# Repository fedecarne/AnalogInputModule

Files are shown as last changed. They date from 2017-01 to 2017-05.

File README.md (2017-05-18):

This is the repo of the Analog Input Module for Bpod.

This repository contains:

-Firmware for Arduino
-Software API for MATLAB
-Design files for the circuit board
-Design files for the enclosure

Requirements:

- ArCOM (https://github.com/sanworks/ArCOM)

Features:

- Arduino-compatible 180MHz ARM Cortex M4 processor (Teensy 3.6)
- 8 x 12 bit Analog inputs (based on Analog Devices AD7327BRUZ)
- Sampling rate: up to 100kHz (1 channel)
- Voltage range settings: -10V:10V, -5V:5V, -2.5V:2.5V, 0V:10V
- 8GB microSD memory for data storage and retrieval
- 2 UART connections to communicate threshold-crossing events to state machine
- Online streaming of digitalized signal through USB or UART
- MATLAB API for easy configuration and usage during behavioral experiments

To get started:
1. Add this folder 'MATLAB' to the MATLAB path.

2. Create your BpodAnalogIn object (you might need to specify the serial port)

	Ain = BpodAnalogIn('COM14');

3. Run Analog Streamer:

	Ain.Streamer

Check out the [documentation](https://sites.google.com/site/bpodanaloginmodule/analog-input-module).

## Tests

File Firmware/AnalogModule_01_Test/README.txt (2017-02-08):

Test version for the rev 1 of the board. 
SD funcionality commented out.

Add acknowledgement bytes

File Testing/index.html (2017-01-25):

## Bpod 8x Analog Input Module

- Overview
- Features
- User Functions
- Examples
- Performance
  - Static Performance
  - Dynamic Performance
- License

### Overview

The AnalogIn Module adds analog acquisition capabilities to the Bpod ecosystem.

### Features

- 8 input channels (12-bit)
- 20kHz+ sampling
- Input range: -10 to +10V (software selectable to +/- 5 or +/-2.5V and 0 to 10V ranges)
- MicroSD card to store up to XXX seconds of acquired data
- USB interface to stream or retrieve data from memory
- Threshold crossing detection (configurable)
- 2 UART serial interfaces connect the module to:
  - The state machine
  - The analog output module (direct interface for closed loop applications)
- I2C interface supported with the I2C module
- Matlab API
- Powered by Arduino Due

### User Functions

User Functions

### Examples

Examples

### Performance

#### Static Performance

The static performance of the board is characterized by the gain error, offset error and maximum absolute error. Below is the result of acquiring a set of static signals across the voltage range of the board.

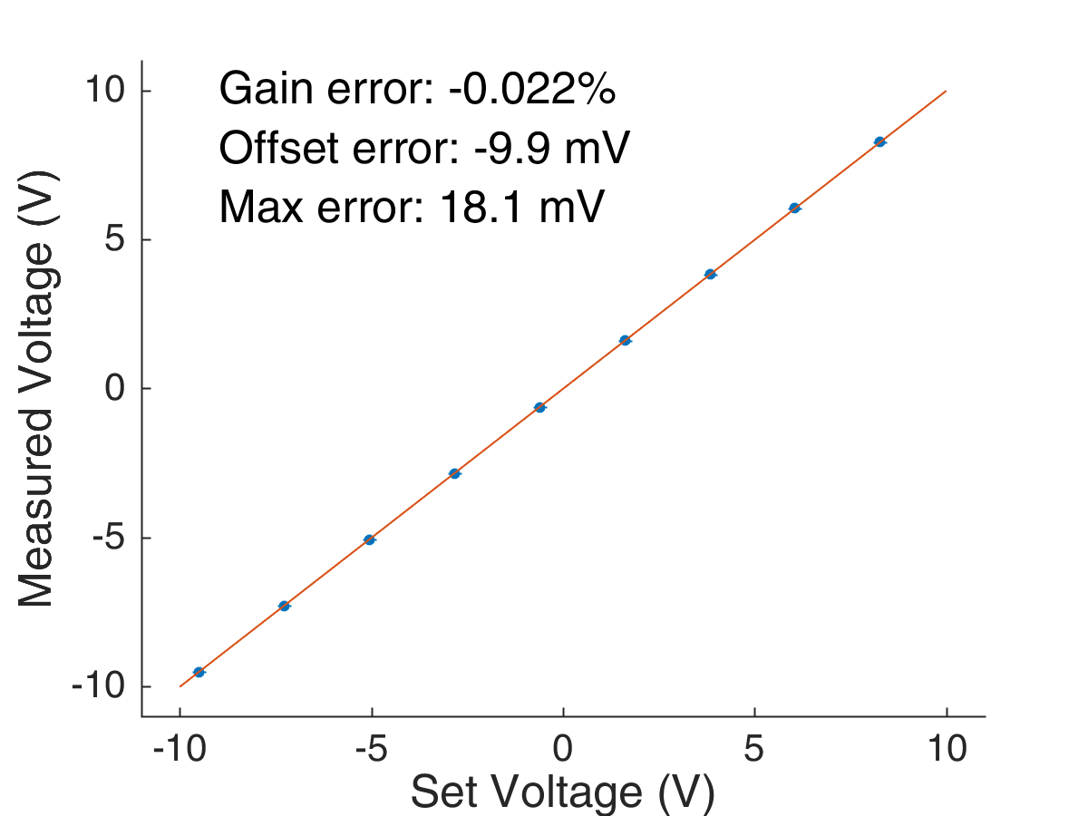
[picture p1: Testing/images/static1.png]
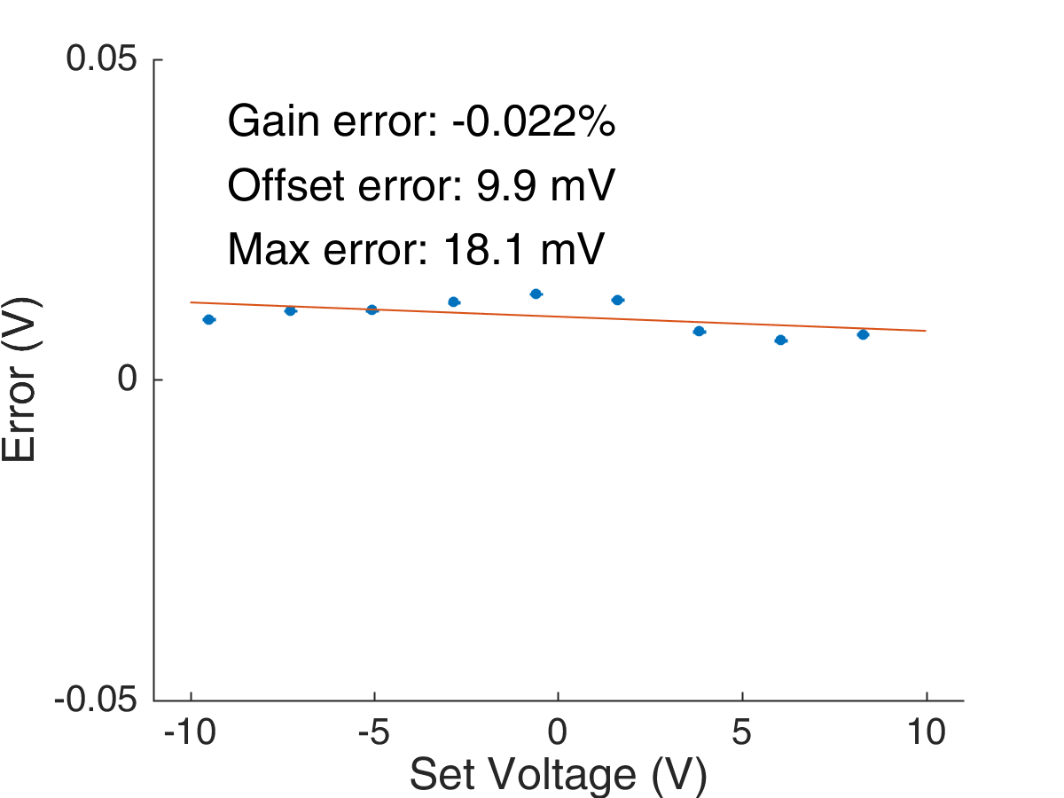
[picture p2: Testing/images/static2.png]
 

#### Dynamic Performance

Signal-to-noise ratio (SNR), total harminic distortion (THD) and signal-to-noise-and-distortion were calculated using a 100Hz signal and sampling at 2kHz.



The SNR does not depend on the sampling frequency up to 20kHz.



### License

License

#### Enjoy! :)

© Copyright? All Rights Reserved.

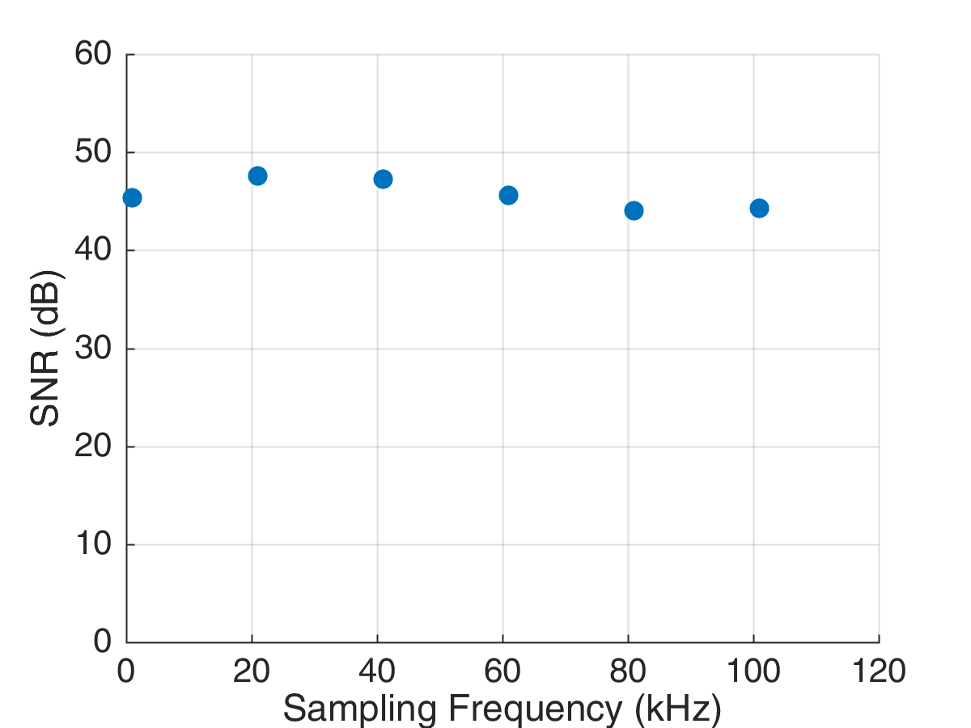
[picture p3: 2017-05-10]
Testing/figs/SnrVsFs.png

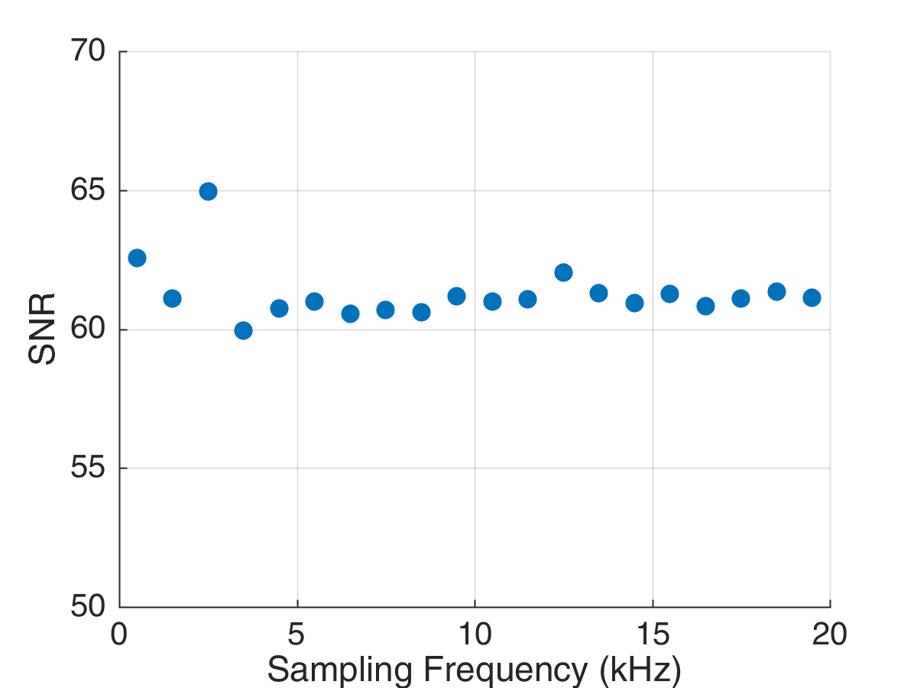
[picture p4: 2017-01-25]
Copy_of_Testing/images/SnrVsFs.png

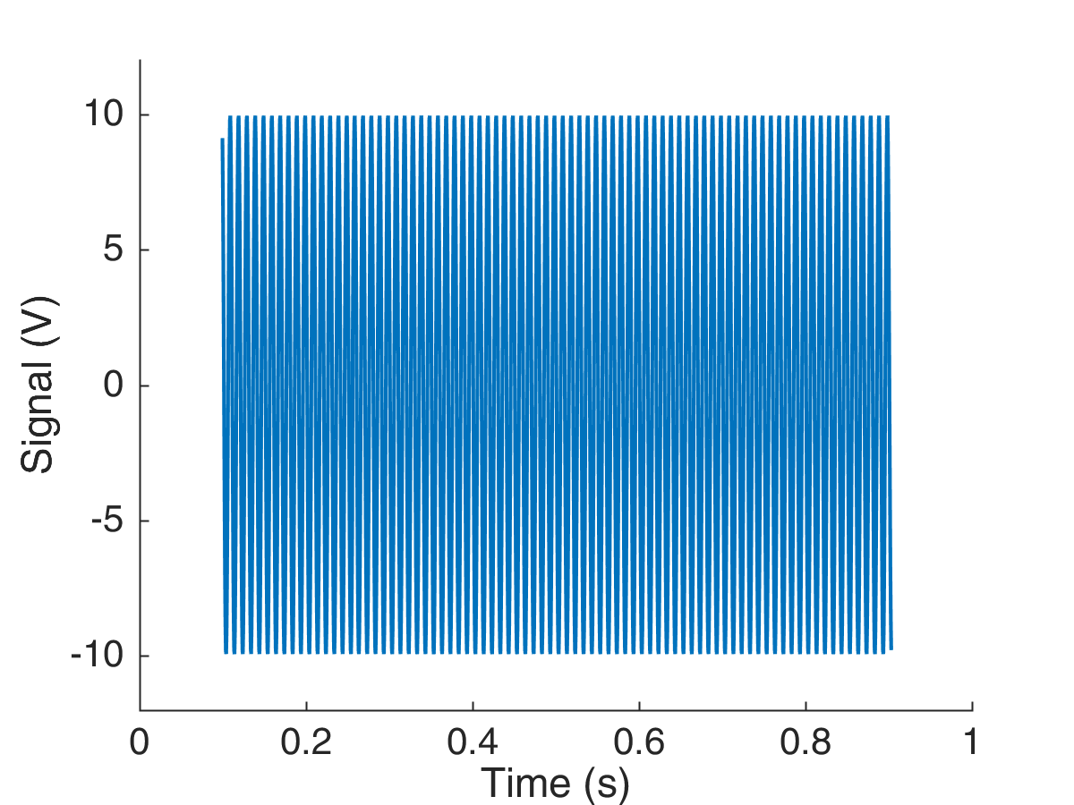
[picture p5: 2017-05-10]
Testing/figs/sine.png

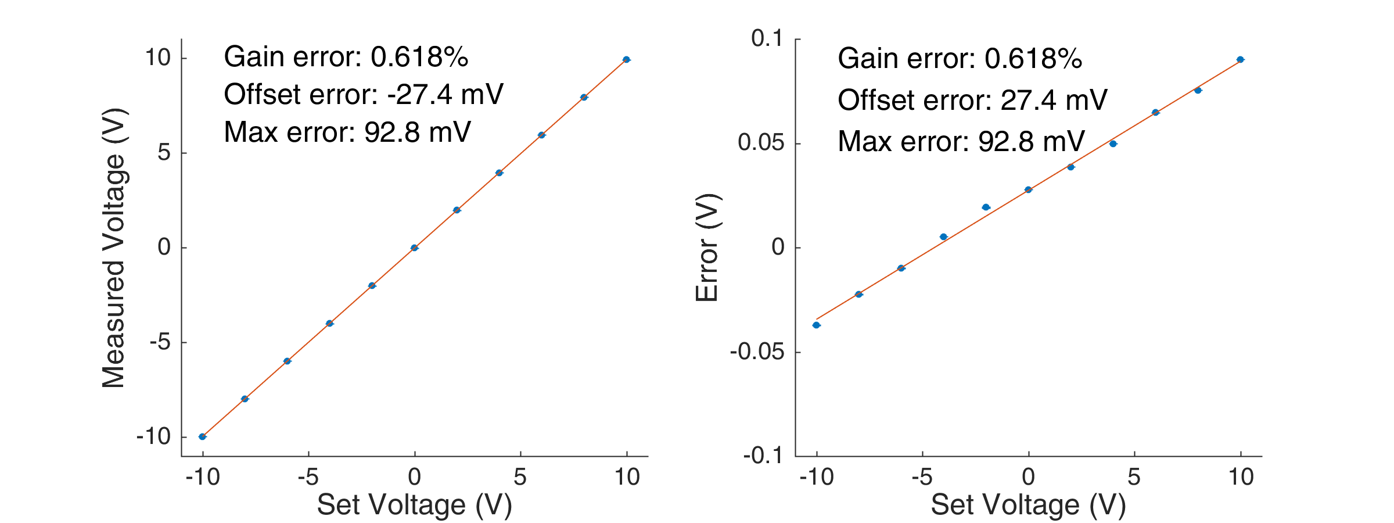
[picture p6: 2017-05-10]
Testing/figs/lite/static.png

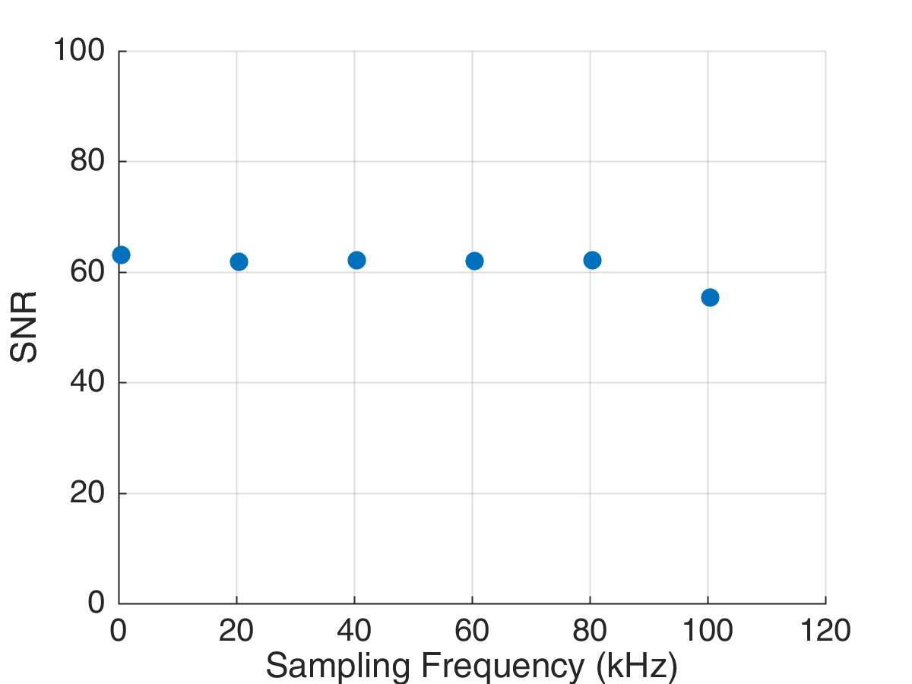
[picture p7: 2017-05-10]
Testing/figs/lite/SnrVsFs.png

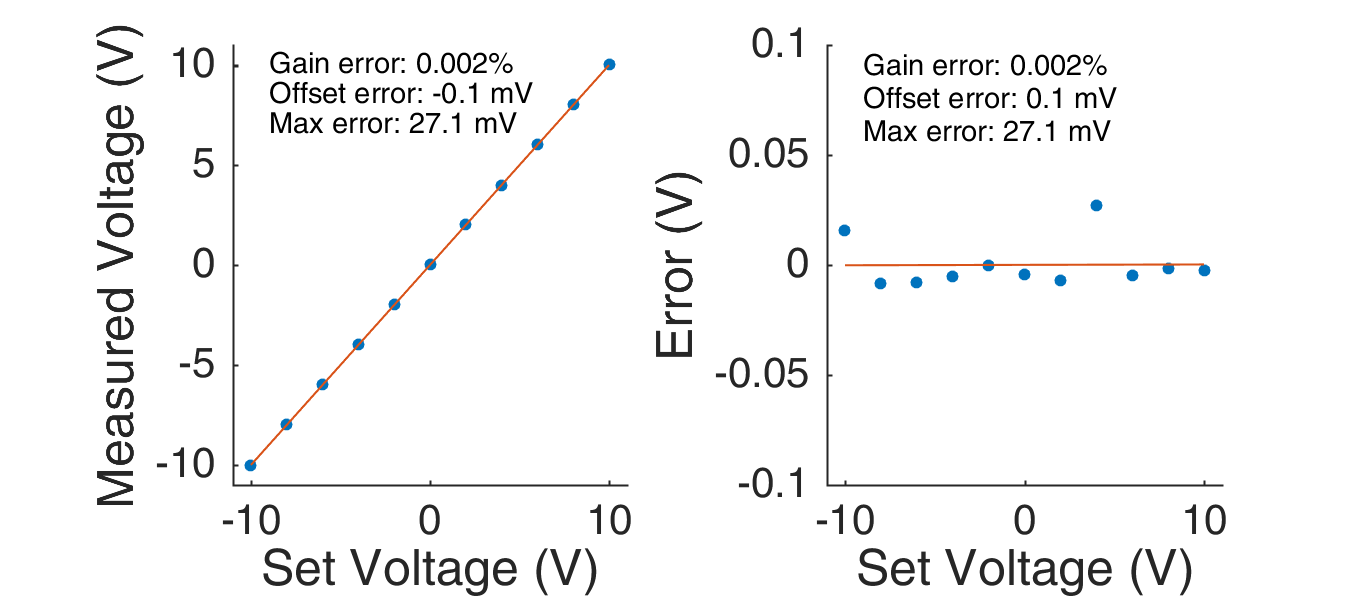
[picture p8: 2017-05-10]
Testing/figs/static.png

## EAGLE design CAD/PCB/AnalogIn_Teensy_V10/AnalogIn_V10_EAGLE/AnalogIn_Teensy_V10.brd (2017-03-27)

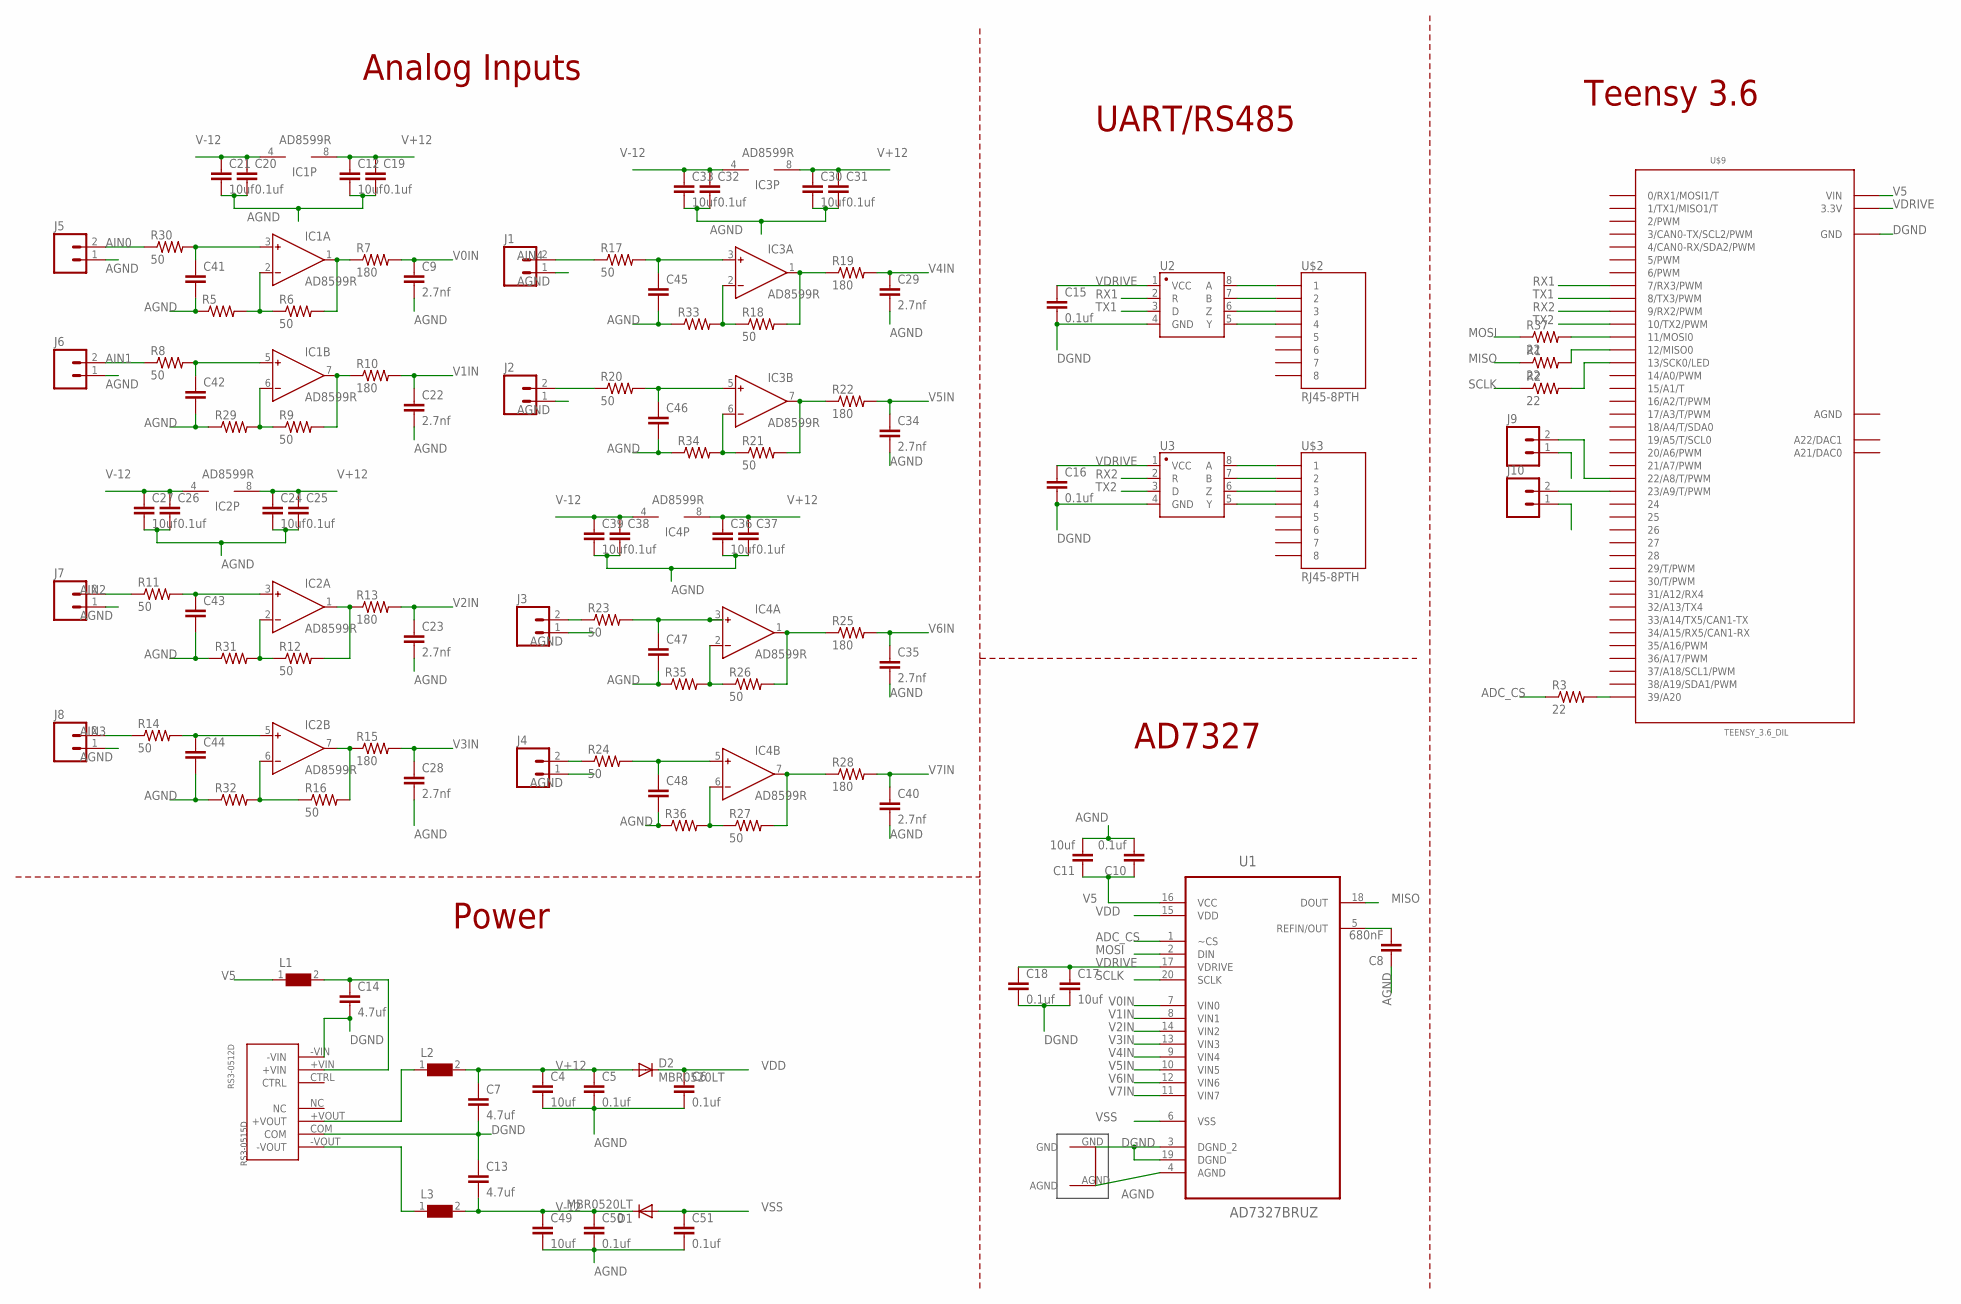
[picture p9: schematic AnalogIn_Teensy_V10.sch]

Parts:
C4, C11, C12, C17, C21, C24, C27, C30, C33, C36, C39, C49: 10uf; 0603-CAP
C5, C6, C10, C15, C16, C18, C19, C20, C25, C26, C31, C32, C37, C38, C50, C51: 0.1uf; 0603-CAP
C7, C13, C14: 4.7uf; 0603-CAP
C8: 680nF; 0603-CAP
C9, C22, C23, C28, C29, C34, C35, C40: 2.7nf; 0603-CAP
C41, C42, C43, C44, C45, C46, C47, C48: CAP0603-CAP; 0603-CAP
D1, D2: MBR0520LT; SOD123
IC1, IC2, IC3, IC4: AD8599R; SO8
J1, J2, J3, J4, J5, J6, J7, J8, J9, J10: M023.5MM; SCREWTERMINAL-3.5MM-2
L1, L2, L3: WE-CBF-742792118_1206; 1206
R1, R2, R3, R37: 22; 0603-RES
R5, R29, R31, R32, R33, R34, R35, R36: RESISTOR0603; 0603-RES
R6, R8, R9, R11, R12, R14, R16, R17, R18, R20, R21, R23, R24, R26, R27, R30: 50; 0603-RES
R7, R10, R13, R15, R19, R22, R25, R28: 180; 0603-RES
RS3-0512D: RS3-0515D
U1: AD7327BRUZ; SOP65P640X120-20N
U2, U3: SN65HVD31DR; SO08
U$2, U$3: RJ45-8PTH; RJ45-8
U$4: GNDPLANESHRT
U$9: TEENSY_3.6_DIL

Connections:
+VOUT: L2.1, RS3-0512D.+VOUT
-VOUT: L3.1, RS3-0512D.-VOUT
ADC_CS: R3.1, U1.1 (~CS)
AGND: C4.2, C5.2, C6.2, C8.1, C9.2, C10.2, C11.2, C12.2, C19.2, C20.2, C21.2, C22.2, C23.2, C24.2, C25.2, C26.2, C27.2, C28.2, C29.2, C30.2, C31.2, C32.2, C33.2, C34.2, C35.2, C36.2, C37.2, C38.2, C39.2, C40.2, C41.2, C42.2, C43.2, C44.2, C45.2, C46.2, C47.2, C48.2, C49.2, C50.2, C51.2, J1.1, J2.1, J3.1, J4.1, J5.1, J6.1, J7.1, J8.1, R5.1, R29.1, R31.1, R32.1, R33.1, R34.1, R35.1, R36.1, U1.4 (AGND), U$4.AGND, U$9.AGND
AIN0: J5.2, R30.1
AIN1: J6.2, R8.1
AIN2: J7.2, R11.1
AIN3: J8.2, R14.1
AIN4: J1.2, R17.1
AIN5: J2.2, R20.1
AIN6: J3.2, R23.1
AIN7: J4.2, R24.1
DGND: C7.2, C13.1, C14.2, C15.2, C16.2, C17.2, C18.2, J9.1, J10.1, RS3-0512D.-VIN, RS3-0512D.COM, U1.3 (DGND_2), U1.19 (DGND), U2.4 (GND), U3.4 (GND), U$4.GND, U$9.GND, U$9.GND1 (GND)
MISO: R1.1, U1.18 (DOUT)
MOSI: R37.1, U1.2 (DIN)
unnamed: U2.6 (Z), U$2.3
unnamed: U2.8 (A), U$2.1
unnamed: U2.5 (Y), U$2.4
unnamed: U2.7 (B), U$2.2
unnamed: U3.6 (Z), U$3.3
unnamed: U3.5 (Y), U$3.4
unnamed: U3.8 (A), U$3.1
unnamed: U3.7 (B), U$3.2
unnamed: R37.2, U$9.11 (11/MOSI0)
unnamed: R1.2, U$9.12 (12/MISO0)
unnamed: C14.1, L1.2, RS3-0512D.+VIN
unnamed: R3.2, U$9.39/A20
unnamed: C41.1, IC1.3 (IN+), R30.2
unnamed: R2.2, U$9.13 (13/SCK0/LED)
unnamed: IC1.2 (IN-), R5.2, R6.1
unnamed: IC1.1 (OUT), R6.2, R7.1
unnamed: J10.2, U$9.23/A9 (23/A9/T/PWM)
unnamed: J9.2, U$9.22/A8 (22/A8/T/PWM)
unnamed: C42.1, IC1.5 (IN+), R8.2
unnamed: IC1.6 (IN-), R9.1, R29.2
unnamed: IC1.7 (OUT), R9.2, R10.1
unnamed: C43.1, IC2.3 (IN+), R11.2
unnamed: IC2.2 (IN-), R12.1, R31.2
unnamed: IC2.1 (OUT), R12.2, R13.1
unnamed: C44.1, IC2.5 (IN+), R14.2
unnamed: IC2.6 (IN-), R16.1, R32.2
unnamed: IC2.7 (OUT), R15.1, R16.2
unnamed: C45.1, IC3.3 (IN+), R17.2
unnamed: IC3.2 (IN-), R18.1, R33.2
unnamed: IC3.1 (OUT), R18.2, R19.1
unnamed: C46.1, IC3.5 (IN+), R20.2
unnamed: IC3.6 (IN-), R21.1, R34.2
unnamed: IC3.7 (OUT), R21.2, R22.1
unnamed: C47.1, IC4.3 (IN+), R23.2
unnamed: IC4.2 (IN-), R26.1, R35.2
unnamed: IC4.1 (OUT), R25.1, R26.2
unnamed: C48.1, IC4.5 (IN+), R24.2
unnamed: IC4.6 (IN-), R27.1, R36.2
unnamed: IC4.7 (OUT), R27.2, R28.1
REF: C8.2, U1.5 (REFIN/OUT)
RX1: U2.2 (R), U$9.7 (7/RX3/PWM)
RX2: U3.2 (R), U$9.9 (9/RX2/PWM)
SCLK: R2.1, U1.20 (SCLK)
TX1: U2.3 (D), U$9.8 (8/TX3/PWM)
TX2: U3.3 (D), U$9.10 (10/TX2/PWM)
V0IN: C9.1, R7.2, U1.7 (VIN0)
V1IN: C22.1, R10.2, U1.8 (VIN1)
V2IN: C23.1, R13.2, U1.14 (VIN2)
V3IN: C28.1, R15.2, U1.13 (VIN3)
V4IN: C29.1, R19.2, U1.9 (VIN4)
V5: C10.1, C11.1, L1.1, U1.16 (VCC), U$9.VIN
V5IN: C34.1, R22.2, U1.10 (VIN5)
V6IN: C35.1, R25.2, U1.12 (VIN6)
V7IN: C40.1, R28.2, U1.11 (VIN7)
V+12: C4.1, C5.1, C7.1, C12.1, C19.1, C24.1, C25.1, C30.1, C31.1, C36.1, C37.1, D2.A, IC1.8 (V+), IC2.8 (V+), IC3.8 (V+), IC4.8 (V+), L2.2
V-12: C13.2, C20.1, C21.1, C26.1, C27.1, C32.1, C33.1, C38.1, C39.1, C49.1, C50.1, D1.C, IC1.4 (V-), IC2.4 (V-), IC3.4 (V-), IC4.4 (V-), L3.2
VDD: C6.1, D2.C, U1.15 (VDD)
VDRIVE: C15.1, C16.1, C17.1, C18.1, U1.17 (VDRIVE), U2.1 (VCC), U3.1 (VCC), U$9.3.3V, U$9.3.3V3 (3.3V)
VSS: C51.1, D1.A, U1.6 (VSS)

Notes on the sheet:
Teensy 3.6
UART/RS485
AD7327
Analog Inputs
Power

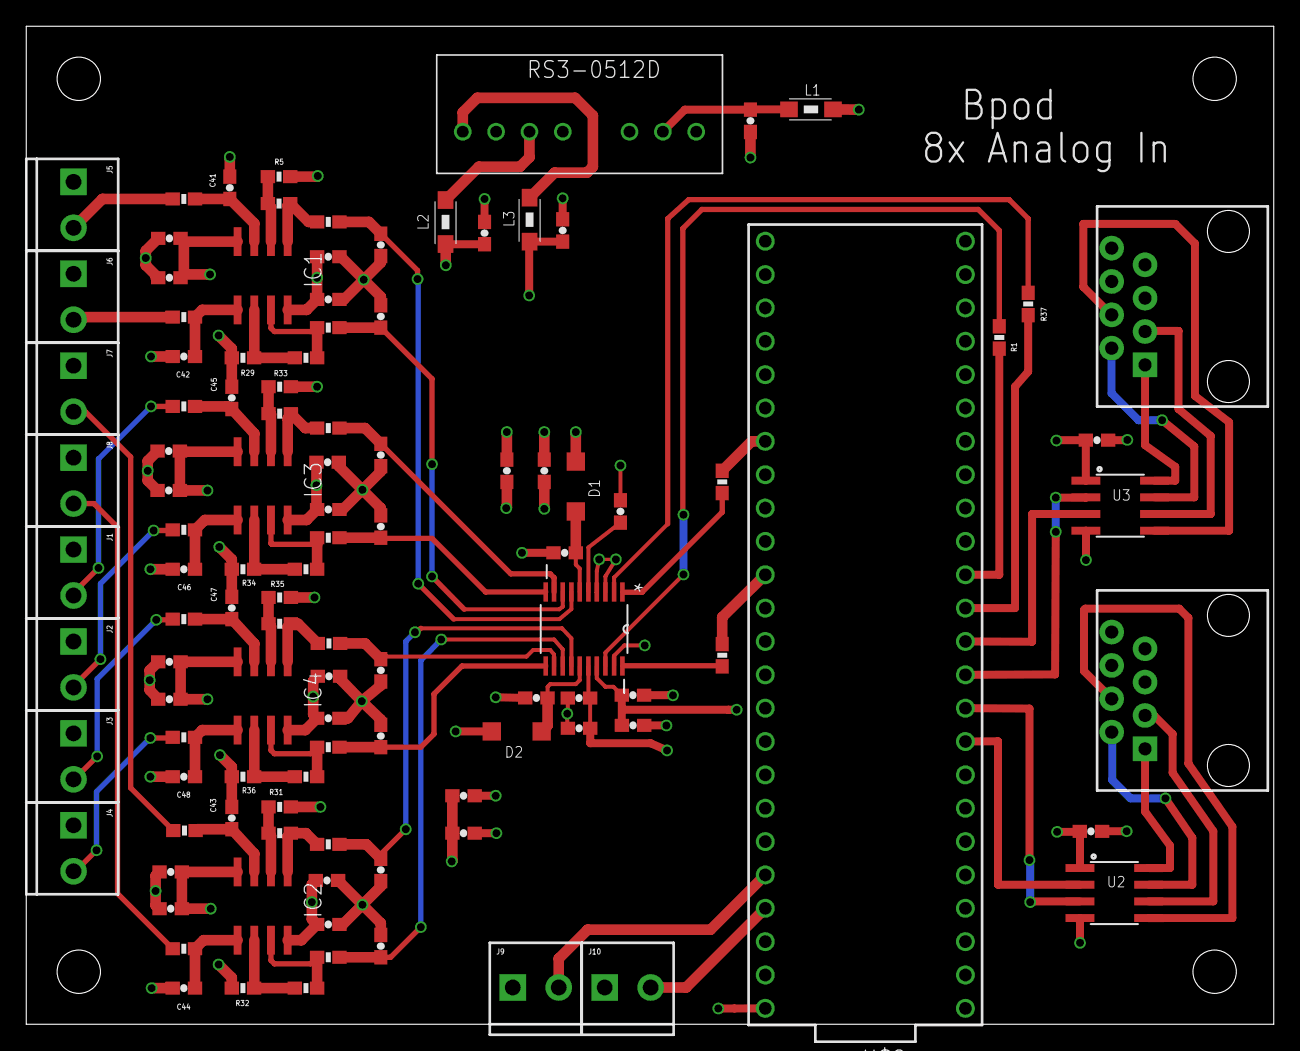
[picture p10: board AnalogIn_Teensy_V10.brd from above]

Board: 4 copper layers, 95.0 x 76.0 mm, 115 parts (0 on the bottom side), 74 nets.

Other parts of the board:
U$5, U$6, U$7, U$8: STAND-OFF

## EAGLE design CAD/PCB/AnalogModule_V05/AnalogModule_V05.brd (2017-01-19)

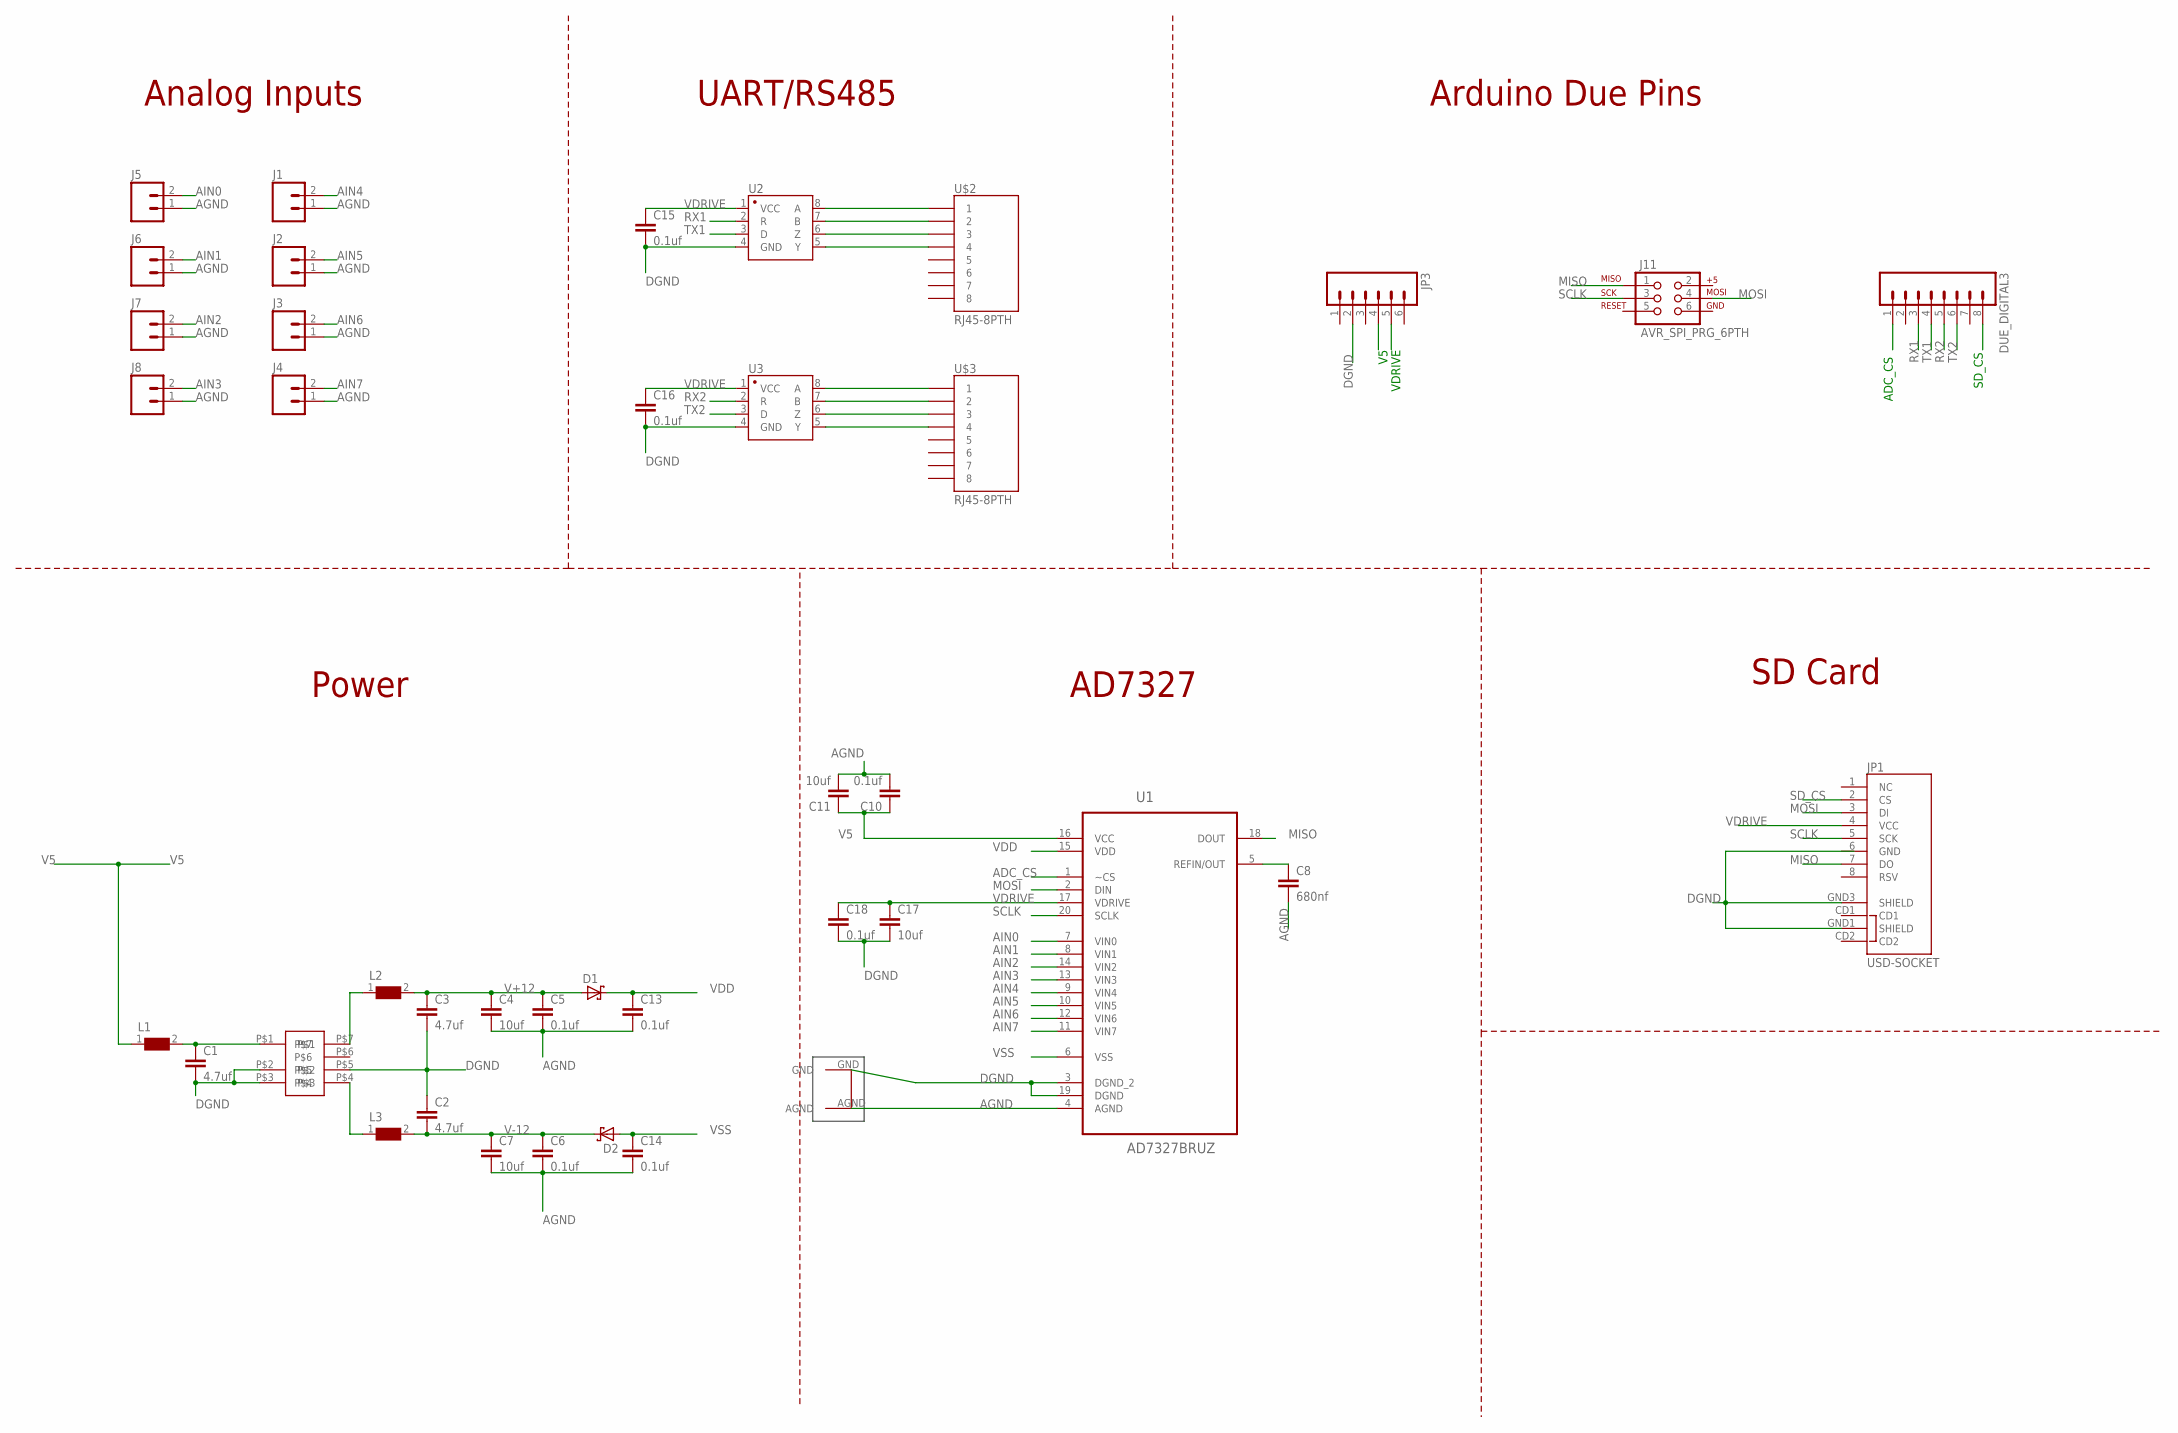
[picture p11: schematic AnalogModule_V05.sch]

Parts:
C1, C2, C3: 4.7uf; 1206
C4, C7: 10uf; 1206
C5, C6, C13, C14: 0.1uf; 1206
C8: 680nf; 1206
C10, C15, C16, C18: 0.1uf; 0603-CAP
C11, C17: 10uf; 0603-CAP
D1, D2: SCHOTTKY-DIODESMD; SMB
DUE_DIGITAL3: M081X08; 1X08
J1, J2, J3, J4, J5, J6, J7, J8: M023.5MM; SCREWTERMINAL-3.5MM-2
J11: AVR_SPI_PRG_6PTH; 2X3
JP1: USD-SOCKET; MICROSD_1:1
JP3: M06SILK_FEMALE_PTH; 1X06
L1, L2, L3: WE-CBF-742792118_1206; 1206
U1: AD7327BRUZ; SOP65P640X120-20N
U2, U3: SN65HVD31DR; SO08
U$1: TDK_LAMBDA_5_TO_BI_12_125MA
U$2, U$3: RJ45-8PTH; RJ45-8
U$4: GNDPLANESHRT

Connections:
ADC_CS: DUE_DIGITAL3.1, U1.1 (~CS)
AGND: C4.2, C5.2, C6.2, C7.2, C8.2, C10.2, C11.2, C13.2, C14.2, J1.1, J2.1, J3.1, J4.1, J5.1, J6.1, J7.1, J8.1, U1.4 (AGND), U$4.AGND
AIN0: J5.2, U1.7 (VIN0)
AIN1: J6.2, U1.8 (VIN1)
AIN2: J7.2, U1.14 (VIN2)
AIN3: J8.2, U1.13 (VIN3)
AIN4: J1.2, U1.9 (VIN4)
AIN5: J2.2, U1.10 (VIN5)
AIN6: J3.2, U1.12 (VIN6)
AIN7: J4.2, U1.11 (VIN7)
DGND: C1.2, C2.1, C3.2, C15.2, C16.2, C17.2, C18.2, JP1.GND1 (SHIELD), JP1.GND3 (SHIELD), JP3.2, U1.3 (DGND_2), U1.19 (DGND), U2.4 (GND), U3.4 (GND), U$1.P$2, U$1.P$3, U$1.P$5, U$4.GND
MISO: J11.1, JP1.7 (DO), U1.18 (DOUT)
MOSI: J11.4, JP1.3 (DI), U1.2 (DIN)
unnamed: U2.6 (Z), U$2.3
unnamed: U2.8 (A), U$2.1
unnamed: U2.5 (Y), U$2.4
unnamed: U2.7 (B), U$2.2
unnamed: U3.6 (Z), U$3.3
unnamed: U3.5 (Y), U$3.4
unnamed: U3.8 (A), U$3.1
unnamed: U3.7 (B), U$3.2
unnamed: C1.1, L1.2, U$1.P$1
unnamed: L2.1, U$1.P$7
unnamed: L3.1, U$1.P$4
REF: C8.1, U1.5 (REFIN/OUT)
RX1: DUE_DIGITAL3.3, U2.2 (R)
RX2: DUE_DIGITAL3.5, U3.2 (R)
SCLK: J11.3, JP1.5 (SCK), U1.20 (SCLK)
SD_CS: DUE_DIGITAL3.8, JP1.2 (CS)
TX1: DUE_DIGITAL3.4, U2.3 (D)
TX2: DUE_DIGITAL3.6, U3.3 (D)
V5: C10.1, C11.1, JP3.4, L1.1, U1.16 (VCC)
V+12: C3.1, C4.1, C5.1, D1.A, L2.2
V-12: C2.2, C6.1, C7.1, D2.C, L3.2
VDD: C13.1, D1.C, U1.15 (VDD)
VDRIVE: C15.1, C16.1, C17.1, C18.1, JP1.4 (VCC), JP3.5, U1.17 (VDRIVE), U2.1 (VCC), U3.1 (VCC)
VSS: C14.1, D2.A, U1.6 (VSS)

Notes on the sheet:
Arduino Due Pins
UART/RS485
SD Card
AD7327
Analog Inputs
Power
ADC_CS
VDRIVE
SD_CS

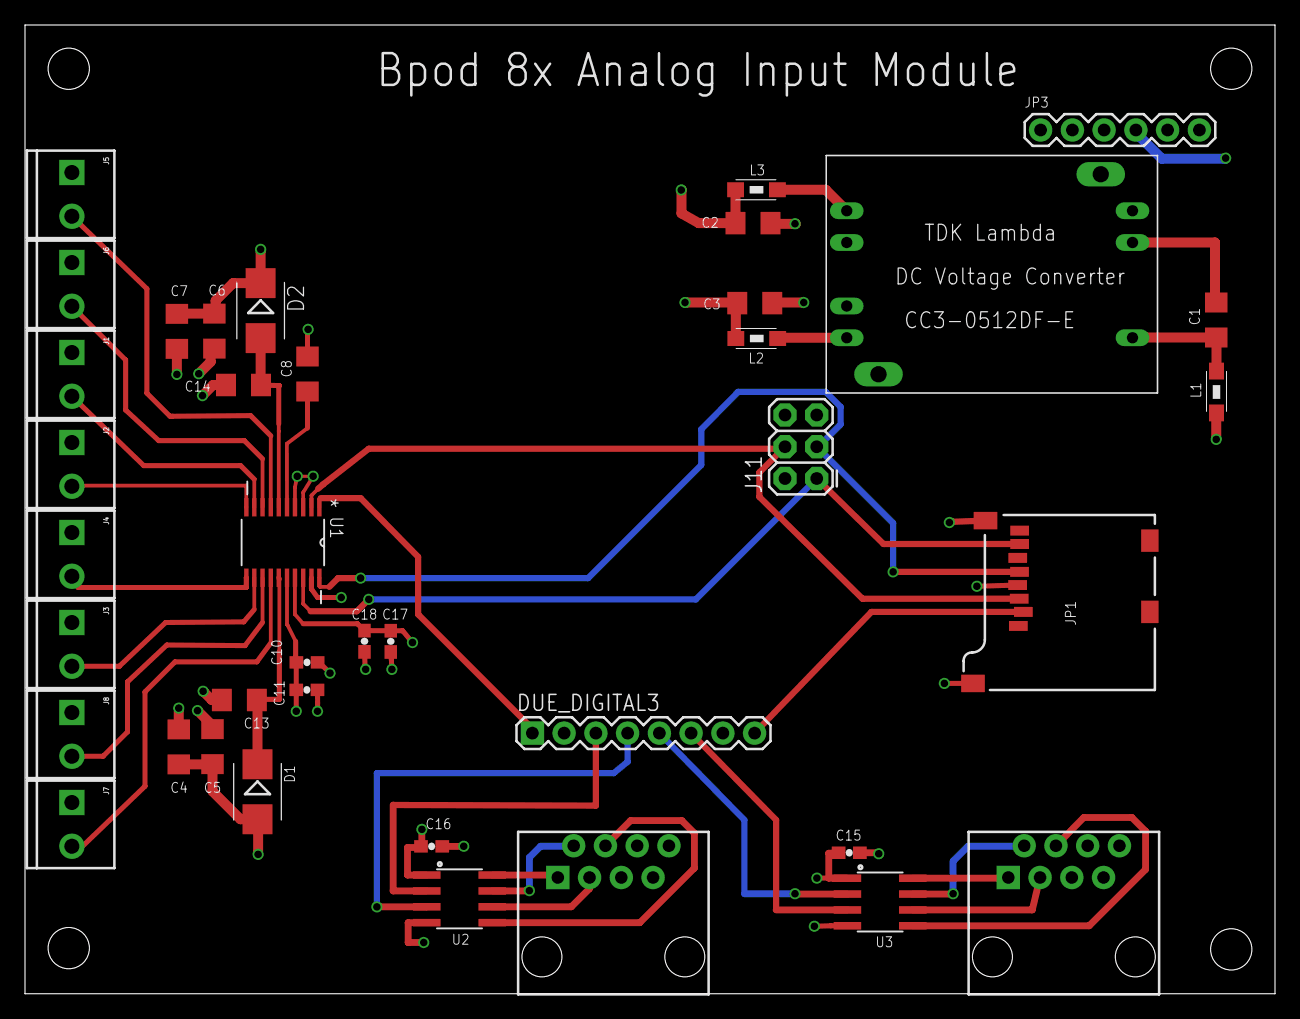
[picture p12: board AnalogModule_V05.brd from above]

Board: 4 copper layers, 100.0 x 77.5 mm, 44 parts (0 on the bottom side), 37 nets.

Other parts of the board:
U$5, U$6, U$7, U$8: STAND-OFF

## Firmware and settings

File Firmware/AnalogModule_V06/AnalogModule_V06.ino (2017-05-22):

// Analog Module firmware v4.0.0
// Federico Carnevale, October 2016

// ** DEPENDENCIES YOU NEED TO INSTALL FIRST **

// This firmware uses the sdFat library, developed by Bill Greiman. (Thanks Bill!!)
// Download it from here: https://github.com/greiman/SdFat
// and copy it to your /Arduino/Libraries folder.

#include "ArCOM.h"
#include "AD7327.h"
#include <SPI.h>
#include <SdFat.h>
SdFatSdioEX SD;

#define SERIAL_TX_BUFFER_SIZE 256
#define SERIAL_RX_BUFFER_SIZE 256

// Module setup
unsigned long FirmwareVersion = 1;
char moduleName[] = "AnalogIn"; // Name of module for manual override UI and state machine assembler

AD7327 AD(39); // ADC ChipSelect
byte adcChipSelectPin = 39; //DISCARD

ArCOM USBCOM(SerialUSB); // Creates an ArCOM object called USBCOM, wrapping SerialUSB
ArCOM StateMachineCOM(Serial3); // Creates an ArCOM object called StateMachineCOM
ArCOM OutputStreamCOM(Serial2);

// Variables that define other hardware pins
byte DebugPin = 18; // Teensy LED

// System objects
SPISettings ADCSettings(10000000, MSBFIRST, SPI_MODE2);
IntervalTimer hardwareTimer; // Hardware timer to ensure even sampling
File DataFile; // File on microSD card, to store waveform data

// Op menu variable
byte opCode = 0; // Serial inputs access an op menu. The op code byte stores the intended operation.
byte opSource = 0; // 0 = op from USB, 1 = op from UART1, 2 = op from UART2. More op code menu options are exposed for USB.
boolean newOpCode = 0; // true if an opCode was read from one of the ports
byte OpMenuByte = 213; // This byte must be the first byte in any serial transmission. Reduces the probability of interference from port-scanning software

// All channels active by default
const byte nPhysicalChannels = 8;
byte nActiveChannels = 8;

// Actions
boolean StreamSignalToUSB = false; // Stream one channel to AnalogStreamer
boolean StreamEventsToUSB = false; // Stream event detection to AnalogStreamer
boolean LoggingDataToSD = false; // Logs active channels to SD card
boolean SendingEventsToBpod = false; // Send threshold crossing by serial port
boolean SendingDataToSerial = false; // Send adc reads through serial port

// State variables
byte ChannelToStream = 0;
byte SelectedADCRange = 0;
boolean acquiring = false; // true if acquiring from the ADC
uint32_t samplingRate = 1000; // in Hz 

// Threshold crossing events
boolean triggered[] = {0, 0, 0, 0, 0, 0, 0, 0};
unsigned long ThresholdValue[] = {0, 0, 0, 0, 0, 0, 0, 0};
unsigned long ResetValue[] = {0, 0, 0, 0, 0, 0, 0, 0};

// SD variables
uint32_t nFullBufferReads = 0; // Number of full buffer reads in transmission
uint32_t nRemainderBytes = 0; // Number of bytes remaining after full transmissions
const uint32_t sdReadBufferSize = 1024; // in bytes
uint8_t sdReadBuffer[sdReadBufferSize*2];

// Other variables
uint16_t adcDigitalValue = 0;
uint32_t nSamplesAcquired = 0;
uint32_t maxSamplesToAcquire = 0; // 0 = infinite
byte VoltageRangeArray[nPhysicalChannels] = {0};

// Error messages stored in flash.
#define error(msg) sd.errorHalt(F(msg))

void setup() {
  pinMode(DebugPin, OUTPUT);
  digitalWrite(DebugPin, HIGH);
  Serial2.begin(1312500); 
  Serial3.begin(1312500);
  SPI.begin();
  SD.begin(); // Initialize microSD card
  hardwareTimer.begin(handler, (1/(double)samplingRate)*1000000); // hardwareTimer is an interval timer object - Teensy 3.6's hardware timer
}


void loop() {
  
}

void handler(void) {
  if (StateMachineCOM.available() > 0) {
    opCode = StateMachineCOM.readByte(); // Read in an op code
    opSource = 1; // UART 1
    newOpCode = true;
  } else if (OutputStreamCOM.available() > 0) {
    opCode = OutputStreamCOM.readByte();
    opSource = 2; // UART 2
    newOpCode = true;
  } else if (USBCOM.available() > 0) {
    if (USBCOM.readByte() == OpMenuByte) {
      opCode = USBCOM.readByte();
      opSource = 0; // USB
    };
    newOpCode = true;
  }

  if (newOpCode) { // If an op byte arrived from one of the serial interfaces
    newOpCode = false;
    switch (opCode) {
      case 'O': {
          if (opSource == 0) {
            USBCOM.writeByte(161); // Send acknowledgement byte
            USBCOM.writeUint32(FirmwareVersion); // Send firmware version
            StreamSignalToUSB = false;
            StreamEventsToUSB = false;
            LoggingDataToSD = false;
            SendingEventsToBpod = false;
            SendingDataToSerial = false;
            DataFile.close();
          }
        } break;

      case 255: // Return Bpod module info
        if (opSource == 1) { // Only returns this info if requested from state machine device
          returnModuleInfo();
        } break;

      case 'S': { // Start USB streaming signal
          StreamSignalToUSB = true;
        } break;

      case 'X': { // Stop USB streaming signal
          StreamSignalToUSB = false;
        } break;

      case 'C': { // Select Channel
          ChannelToStream = USBCOM.readByte(); // Read the command byte (an op code for the operation to execute)
          if (ChannelToStream > 7) {
            ChannelToStream = 0;
          }
        } break;

      case 'R': { // Select ADC Voltage range
          USBCOM.readByteArray(VoltageRangeArray, nActiveChannels);
          for (int i = 0; i > nPhysicalChannels; i++) {
            AD.setRange(i, VoltageRangeArray[i]);
          }
        } break;

      case 'A': { // Set number of active channels
          nActiveChannels = USBCOM.readByte();
          USBCOM.writeByte(1); // Send confirm byte
        } break;

      case 'E': { // Start streaming events
          StreamEventsToUSB = true;
          for (int i = 0; i < nPhysicalChannels; i++) {
            triggered[i] = 0;
          }
        } break;

      case 'Y': { // Stop  streaming events
          StreamEventsToUSB = false;
          stopAcquiringIfNotActive();
        } break;

      case 'B': { // Set reset values
          for (int i = 0; i < nPhysicalChannels; i++) {
            ResetValue[i] = USBCOM.readUint32();
          }
        } break;

      case 'T': { // Set thresholds
          for (int i = 0; i < nPhysicalChannels; i++) {
            ThresholdValue[i] = USBCOM.readUint32();
          }
        } break;

      case 'L': { // Start logging data
          //StateMachineCOM.writeChar(1); // Uncomment to send start logging flag to bpod for diagnostics (NOTE: may be confused with a threshold event if streaming events)
          StartLogData();
        } break;

      case 'Z': { // Stop  logging data
          StopLogData();
          stopAcquiringIfNotActive();
        } break;

      case 'D': { // Read SD card and send data

          LoggingDataToSD = false;
          DataFile.close();
          unsigned long d0;
          DataFile = SD.open("Data.wfm", FILE_WRITE);
          DataFile.seekSet(0);
          if (nSamplesAcquired*2 > sdReadBufferSize) {
            nFullBufferReads = (unsigned long)(floor(((double)nSamplesAcquired)*double(nActiveChannels)*2 / (double)sdReadBufferSize));
          } else {
            nFullBufferReads = 0;
          }
          USBCOM.writeUint32(nSamplesAcquired);     
          for (int i = 0; i < nFullBufferReads; i++) { // Full buffer transfers; skipped if nFullBufferReads = 0
            DataFile.read(sdReadBuffer, sdReadBufferSize);
            USBCOM.writeByteArray(sdReadBuffer, sdReadBufferSize);
          }
          nRemainderBytes = (nSamplesAcquired*nActiveChannels*2)-(nFullBufferReads*sdReadBufferSize);
          if (nRemainderBytes > 0) {
            DataFile.read(sdReadBuffer, nRemainderBytes);
            USBCOM.writeByteArray(sdReadBuffer, nRemainderBytes);     
          }
          DataFile.close();
        } break;

      case 'P': { // Change sampling frequency
          samplingRate = USBCOM.readUint32();
          hardwareTimer.end();
          hardwareTimer.begin(handler, (1/(double)samplingRate)*1000000);
        } break;

      case 'N': { // Start sending threshold crossing events to bpod
          for (int i = 0; i < nPhysicalChannels; i++) {
            triggered[i] = 0;
          }
          SendingEventsToBpod = true;
          acquiring = true;
        } break;

      case 'M': { // Stop sending threshold crossing events to bpod
          SendingEventsToBpod = false;
          stopAcquiringIfNotActive();
        } break;

      case 'H': { // Start sending adc reads to serial port
          SendingDataToSerial = true;
          acquiring = true;
        } break;

      case 'I': { // Stop  sending adc reads to serial port
          SendingDataToSerial = false;
          stopAcquiringIfNotActive();
        } break;

      case 'W': {
        maxSamplesToAcquire = USBCOM.readUint32();
        USBCOM.writeByte(1);
      } break;
    }// end switch(opCode)
  }// end newOpCode

  if (acquiring) {
    AD.readADC(); // Reads all active channels and stores the result in a buffer in the AD object: AD.analogData[]
  }

  // Streaming data with AnalogStreamer
  if (StreamSignalToUSB) {
    USBCOM.writeUint16(AD.analogData.uint16[ChannelToStream]);
  }

  // Streaming threshold crossings with AnalogStreamer
  if (StreamEventsToUSB) {
    USBCOM.writeUint8(StreamThresholdCrossing());
  }
  
  if (LoggingDataToSD) {
    LogData();
  }
  if (SendingEventsToBpod) {
    SendThresholdCrossingEvents();
  }
  if (SendingDataToSerial) {
    SendDataToSerial();
  }
} // End main timer loop

// Detect thresholds in active channels and send events to Bpod
void SendThresholdCrossingEvents() {

  // nActiveChannels has the number of active channels
  for (int i = 0; i < nActiveChannels; i++) {
    if (triggered[i] == 0) {
      if (AD.analogData.uint16[i] > ThresholdValue[i]) {
        StateMachineCOM.writeByte(i + 1);
        triggered[i] = 1;
      }
    } else {
      if (AD.analogData.uint16[i] < ResetValue[i]) {
        triggered[i] = 0;
      }
    }
  }
}

// Send data to serial port
void SendDataToSerial() {
  StateMachineCOM.writeByte('R');
  StateMachineCOM.writeUint16Array(AD.analogData.uint16, nActiveChannels);
}

// Log data
void LogData() {
  //Write data to SD
  unsigned long Pos = 0;
  for (int i = 0; i < nActiveChannels; i++) {
    DataFile.write(AD.analogData.uint8[Pos]);
    DataFile.write(AD.analogData.uint8[Pos+1]);
    Pos += 2;
  }
  nSamplesAcquired++;
  if (nSamplesAcquired == maxSamplesToAcquire) {
    StopLogData();
    stopAcquiringIfNotActive();
  }
}

// Log data
void StartLogData() {
  LoggingDataToSD = true;
  acquiring = true;
  SD.remove("Data.wfm");
  DataFile = SD.open("Data.wfm", FILE_WRITE);
  nSamplesAcquired = 0;
}

void StopLogData() {

  LoggingDataToSD = false;
  StateMachineCOM.writeByte(10); // Send stop logging flag to bpod

  // Close logging file
  DataFile.close();
}

void stopAcquiringIfNotActive() {
  if (!StreamEventsToUSB && !LoggingDataToSD && !SendingEventsToBpod && !SendingDataToSerial) {
    acquiring = false;
  }
}

//Function to detect thresholds read all channels of the ADC in sequence
byte StreamThresholdCrossing() {
  byte ThresholdCrossed = 0;
  for (int i = 0; i < nPhysicalChannels; i++) {
    if (triggered[i] == 0) {
      if (AD.analogData.uint16[i] > ThresholdValue[i]) {
        ThresholdCrossed = ThresholdCrossed | 1 << i;
        triggered[i] = 1;
      } else {
        ThresholdCrossed = ThresholdCrossed | 0 << i;
      }
    } else {
      ThresholdCrossed = ThresholdCrossed | 0 << i;

      if (AD.analogData.uint16[i] < ResetValue[i]) {
        triggered[i] = 0;
      }
    }
  }
  return ThresholdCrossed; // Returns the value from the function
}

void returnModuleInfo() {
  StateMachineCOM.writeByte(65); // Acknowledge
  StateMachineCOM.writeUint32(FirmwareVersion); // 4-byte firmware version
  StateMachineCOM.writeByte(sizeof(moduleName) - 1); // Length of module name
  StateMachineCOM.writeCharArray(moduleName, sizeof(moduleName) - 1); // Module name
  StateMachineCOM.writeByte(0);
}

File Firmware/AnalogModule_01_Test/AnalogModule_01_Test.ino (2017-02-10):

// Analog Module firmware v1.0.0
// Federico Carnevale, October 2016
//
// ** DEPENDENCIES YOU NEED TO INSTALL FIRST **

// 1. This firmware uses the open source DueTimer library, developed by Ivan Seidel. (Thanks Ivan!!)
// Download it from here: https://github.com/ivanseidel/DueTimer
// and copy it to your /Arduino/Libraries folder.
// The DueTimer library is open source, and protected by the MIT License.

// 2. This firmware uses the sdFat library, developed by Bill Greiman. (Thanks Bill!!)
// Download it from here: https://github.com/greiman/SdFat
// and copy it to your /Arduino/Libraries folder.

// ** Next, upload the firmware to Arduino Due **
// See here for driver installation and upload instructions: https://www.arduino.cc/en/Guide/ArduinoDue


#include <DueTimer.h>
#include <stdio.h>
#include <stdint.h>
#include <SPI.h>

//#include <SdFat.h>
//#include <SdFatUtil.h>

#include <ArCOM.h> // ArCOM is a serial interface wrapper developed by Sanworks, to streamline transmission of datatypes and arrays over serial

ArCOM myUSB(SerialUSB); // Creates an ArCOM object called myUSB, wrapping SerialUSB

// Define macros for compressing sequential bytes read from the serial port into long and short ints
#define makeUnsignedLong(msb, byte2, byte3, lsb) ((msb << 24) | (byte2 << 16) | (byte3 << 8) | (lsb))
#define makeUnsignedShort(msb, lsb) ((msb << 8) | (lsb))

const uint32_t SAMPLE_INTERVAL_US = 250000;
#define CSV_DELIM ','

byte FirmwareVersion = 1;

// Variables that define other hardware pins
byte adcChipSelectPin = 21; // set pin 8 as the chip select for the ADC:
//byte SDChipSelectPin = 14; // set pin 4 as the chip select for the SD

// Variables for SPI bus
SPISettings ADCSettings(1000000, MSBFIRST, SPI_MODE2);

// Relavant bitmasks for data value and channel address
byte adcValueMask_byte1 = 0b00111111;
byte adcValueMask_byte2 = 0b11111111;
byte adcAddressMask = 0b11100000;

// Default values for ADC

// All channels active by default
byte ActiveChannelsByte = 255; //all channels
int ActiveChannelsList[] = {0,1,2,3,4,5,6,7};
int nActiveChannels = 8;

// Sets control register (8 single-ended inputs, straight binary, internal reference, no sequence)
byte adcControlRegister_byte1 = 0b10000000; 
byte adcControlRegister_byte2 = 0b00110000;

byte adcSequenceRegister_byte1 = 0b11111111;
byte adcSequenceRegister_byte2 = 0b11100000;

byte adcRangeRegister1_byte1 = 0b10111111; // Sets channels 0-3 range to 0V - 10V
byte adcRangeRegister1_byte2 = 0b11100000; // Sets channels 0-3 range to 0V - 10V
byte adcRangeRegister2_byte1 = 0b11011111;  // Sets channels 4-7 range to 0V - 10V
byte adcRangeRegister2_byte2 = 0b11100000;  // Sets channels 4-7 range to 0V - 10V
  
  
// Variables used in programming
byte OpMenuByte = 213; // This byte must be the first byte in any serial transmission. Reduces the probability of interference from port-scanning software

// Actions
boolean StreamSignalToUSB = 0; // Stream one channel to AnalogStreamer
boolean StreamEventsToUSB = 0; // Stream event detection to AnalogStreamer
boolean LoggingDataToSD = 0; // Logs active channels to SD card
boolean SendingEventsToBpod = 0; // Send threshold crossing by serial port

byte ChannelToStream = 0;
byte SelectedADCRange = 0;

byte BrokenBytes[4] = {0}; // Used to store sequential bytes when converting bytes to short and long ints
byte inByte; byte inByte2; byte inByte3; byte inByte4; byte CommandByte; byte BpodCommandByte;

boolean triggered[] = {0,0,0,0,0,0,0,0};
unsigned long ThresholdValue[] = {0,0,0,0,0,0,0,0};
unsigned long ResetValue[] = {0,0,0,0,0,0,0,0};


// SD variables
uint8_t buf[1];
uint8_t buf2[2];
uint8_t buf4[4];

#define FILE_BASE_NAME "Data2"
unsigned long SystemTime = 0;

//SdFat sd;
//SdFile DataFile;

char fileName[13] = FILE_BASE_NAME "00.csv";
 
// Other variables
int ConnectedToApp = 0; // 0 if disconnected, 1 if connected
void handler(void);
int adcDigitalValue = 0;

unsigned long LoggedData[20000];

// Error messages stored in flash.
#define error(msg) sd.errorHalt(F(msg))

void setup() {

  pinMode(13, OUTPUT);  
  pinMode(adcChipSelectPin, OUTPUT);
  digitalWrite(adcChipSelectPin, HIGH);
  
  //pinMode(SDChipSelectPin, OUTPUT); // microSD setup
  
  SerialUSB.begin(115200); // Initialize Serial USB interface at 115.2kbps
  Serial1.begin(1312500); // Initialize UART serial port to talk to bpod
  
  SPI.begin();

  SetDefaultADCSettings();
  
  // Initialize the SD card at SPI_HALF_SPEED to avoid bus errors with
  // breadboards.  use SPI_FULL_SPEED for better performance.
//  if (!sd.begin(SDChipSelectPin, SPI_HALF_SPEED)) { 
//  //if (!sd.begin(SDChipSelectPin, SPI_FULL_SPEED)) {
//    sd.initErrorHalt();
//  }
   
  Timer3.attachInterrupt(handler);
  Timer3.start(SAMPLE_INTERVAL_US); // Calls handler precisely every 50us

}

//------------------------------------------------------------------------------
void loop() {
}
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

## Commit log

2017-01-16 Added files from local computer to repo.
    [AnalogModule_V05.brd, AnalogModule_V05.sch]
2017-01-19 Added rev1 board test firmware. No SD functionality
2017-01-25 Update :)
    [AnalogIn_Teensy_V05.brd, AnalogIn_Teensy_V05.sch, AnalogModule_V05.brd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]
2017-01-27 Teensy design and OOP Matlab code
2017-01-30 Teensy version with signal conditioning
    [AnalogIn_Teensy_V10.brd, AnalogIn_Teensy_V10.sch]
2017-02-06 Update TeensyV10 board
    [AnalogIn_Teensy_V10.brd, AnalogIn_Teensy_V10.sch, AnalogModule_V05.brd]
2017-02-07 Update Teensy verion
    [AnalogIn_Teensy_V10.brd, AnalogIn_Teensy_V10.sch]
2017-02-08 Teensy board
    [AnalogIn_Teensy_V10.brd, AnalogIn_Teensy_V10.sch]
2017-05-14 Fixed bugs in Example2
    [AnalogModule_V04.ino]
2017-05-14 Fixed SPI speed and retrieve function
    [AD7327.cpp, AnalogModule_V04.ino]
2017-05-18 Josh's changes
    - retrieving schema
    - firmware
    - voltage range attribute
    - etc
2017-05-20 -Fixed module name length data type in firmware
    [AnalogModule_V05.ino]
2017-05-22 -Rewrote AD7327 library. Major changes: uses bitSet, bitClear and bitGet methods to set register bits (for clarity at the expense of speed), uses spi.write16 to write 16-bit ints (for speed), uses 1-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
    [AD7327.cpp, AnalogModule_V06.ino]

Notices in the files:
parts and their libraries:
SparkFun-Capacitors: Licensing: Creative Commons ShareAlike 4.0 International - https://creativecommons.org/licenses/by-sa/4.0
